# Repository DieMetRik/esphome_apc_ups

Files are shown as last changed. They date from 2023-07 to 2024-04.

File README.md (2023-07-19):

# UPS APC <-> ESP32 <-> Home Assistant

**disclaimer:** Сразу скажу, что я не проф. программист, поэтому код может где то быть не элегантен.

Мой UPS: **APC by Schneider Electric Smart-UPS SUA1500I**, Имеет на борту USB и RS232

За основу протокола: http://www.apcupsd.org/manual/#apc-smart-protocol

Cхема кабеля: http://www.apcupsd.org/manual/#id40

По итогу все работает, интервал обновления ~10 сек

Было проведено порядка 10 различных схем подключения и только на 10-11 получилось.

**Что тянется:**
* Входное напряжение
* Выходное напряжение
* Напряжение батареи
* Уровень заряд батареи
* Оставшееся время на батарее
* Нагрузка
* Температура
* Частота сети
* Последнее сообщение с UPS
* Статус bit 

**Что считается и передает в esp32:**
* Статус: ONLINE/OFFLINE/ONBATT
* Дата последнего обновления данных (время берется по NTP, нужно ESP в интернет)
* Кол-во переходов с ONLINE на ONBATT (Сохраняется в EEPROM)

Использовал сделующие компоненты:
* ESP32 38pin
* Logic Level shifter
* TTL <-> RS232
* DB9 male connector

Покупал тут:
* Esp32: https://aliexpress.ru/item/32864722159.html
* Logic Level shifter: https://aliexpress.ru/item/32247463702.html
* Вот эта у меня не заработала: https://pcus.ru/modul-preobrazovaniya-ttl-uart-v-rs232
* А вот эта норм: https://pcus.ru/max3232-preobrazovatel-rs232-db9-uart-ttl

Схема подключения:
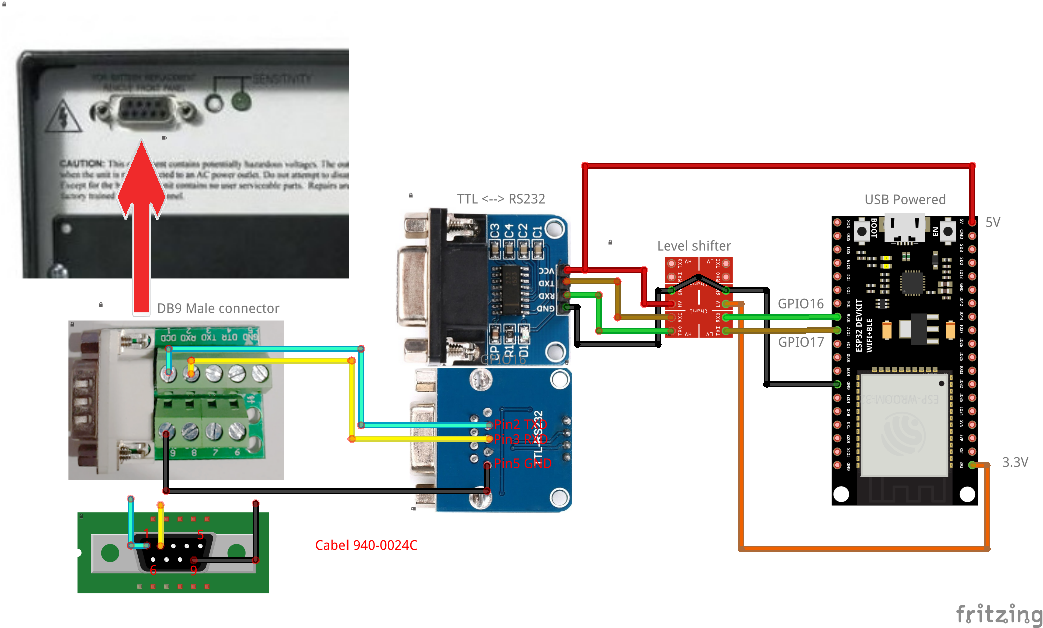
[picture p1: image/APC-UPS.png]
Image alt


Кабель:

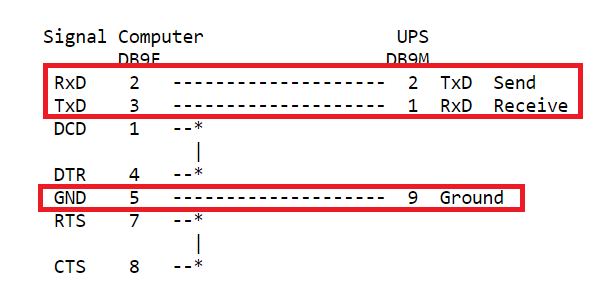
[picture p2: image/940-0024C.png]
Image alt


Код для ESPhome в файле /esp32/ups-apc-protocol.yaml
Папку /esp32/apc положить на сервер: /config/esphome/apc/

Пример для Home Assistant:

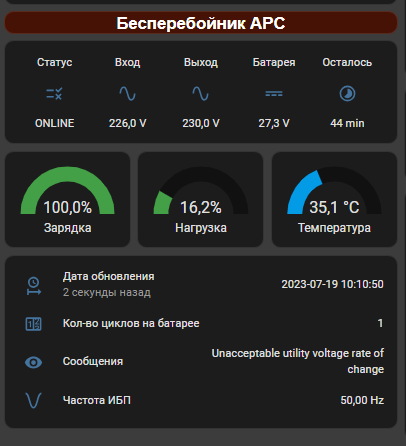
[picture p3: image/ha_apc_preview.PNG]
Image alt


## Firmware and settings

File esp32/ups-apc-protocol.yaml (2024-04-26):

substitutions:
  device_name: "ups-apc-protocol"
  device_ip: 192.168.1.137
  device_description: "Мониторинг бесперебойника"
  tx_pin: GPIO17
  rx_pin: GPIO16

esphome:
  name: ${device_name}
  name_add_mac_suffix: false
  includes:
    - /config/esphome/apc/upc_apc.h #Указываем свой путь до файла
  libraries:
    - EEPROM

  comment: ${device_description}
  on_boot:
    if:
      condition:
        time.has_time:
      then:
        - logger.log: Time has been set and is valid!

esp32:
  board: esp32dev
  framework:
    type: arduino

web_server:
  port: 80
  include_internal: true
  version: 3
  auth:
    username: !secret web_server_login
    password: !secret web_server_password

# Enable logging
logger:
  level: debug

# Enable Home Assistant API
api:
  encryption:
    key: !secret encryption_key_ups_apt_protocol

ota:
  password: !secret ota_password

wifi:
  ssid: !secret wifi_ssid
  password: !secret wifi_password

  # Optional manual IP
  manual_ip:
    static_ip: ${device_ip}
    gateway: !secret wifi_gateway
    subnet: !secret wifi_subnet
    dns1: !secret wifi_dns1
    dns2: !secret wifi_dns2

  # Enable fallback hotspot (captive portal) in case wifi connection fails
  ap:
    ssid: ${device_name}
    password: !secret ap_password

captive_portal:

time:
  - platform: sntp
    servers: "192.168.1.30"
    id: sntp_time
    timezone: Europe/Moscow

text_sensor:
  - platform: version
    name: ${device_name}_version
    hide_timestamp: true

  - platform: template
    name: ${device_name}_uptime
    id: uptime_human
    icon: mdi:clock-start

  - platform: template
    name: ${device_name}_status
    id: Status
    lambda: "return {};"

  - platform: template     
    id: last_updated_datetime
    name: ${device_name}_last_updated_datetime
    icon: mdi:clock-start

  - platform: template     
    id: last_self_test_datetime
    name: ${device_name}_last_self_test_datetime
    icon: mdi:clock-start

  - platform: template     
    id: sensitivity
    name: ${device_name}_sensitivity
    icon: mdi:clock-start

  - platform: template
    name: ${device_name}_self_test_result
    id: self_test_result
    lambda: "return {};"
    on_raw_value:
      then:
      - text_sensor.template.publish:
          id: last_self_test_datetime
          state:  !lambda |-
              char str[25];
              time_t currTime = id(sntp_time).now().timestamp;
              strftime(str, sizeof(str), "%Y-%m-%d %H:%M:%S", localtime(&currTime));
              //strftime(str, sizeof(str), "%Y-%m-%dT%H:%M:%S.000Z", gmtime(&currTime));
              return (std::string) str;
    
  - platform: template
    name: ${device_name}_last_cause
    id: Last_cause
    lambda: "return {};"
    on_raw_value:
      then:
      - text_sensor.template.publish:
          id: last_updated_datetime
          state:  !lambda |-
              char str[25];
              time_t currTime = id(sntp_time).now().timestamp;
              strftime(str, sizeof(str), "%Y-%m-%d %H:%M:%S", localtime(&currTime));
              //strftime(str, sizeof(str), "%Y-%m-%dT%H:%M:%S.000Z", gmtime(&currTime));
              return (std::string) str;


sensor:
  - platform: wifi_signal
    name: ${device_name}_wifi_signal
    update_interval: 60s
    entity_category: "diagnostic"
    device_class: ""
    unit_of_measurement: "%"
    filters:
      - calibrate_polynomial:
          degree: 2
          datapoints:
              - -60.0 -> 67.0
              - -59.0 -> 68.0
              - -57.0 -> 71.0
              - -56.0 -> 72.0
              - -55.0 -> 73.0
              - -30.0 -> 96.0
              - -28.0 -> 98.0

  - platform: uptime
    name: ${device_name}_uptime
    id: uptime_sensor
    internal: true
    on_raw_value:
      then:
        - text_sensor.template.publish:
            id: uptime_human
            state: !lambda |-
              int seconds = round(id(uptime_sensor).raw_state);
              int days = seconds / (24 * 3600);
              seconds = seconds % (24 * 3600);
              int hours = seconds / 3600;
              seconds = seconds % 3600;
              int minutes = seconds /  60;
              seconds = seconds % 60;
              return (
                (days ? to_string(days) + "d " : "") +
                (hours ? to_string(hours) + "h " : "") +
                (minutes ? to_string(minutes) + "m " : "") +
                (to_string(seconds) + "s")
              ).c_str();

  - platform: template #estimated_runtime
    id: Estimated_runtime
    name: ${device_name}_estimated_runtime
    unit_of_measurement: "min"
    accuracy_decimals: 0
    lambda: "return {};"


  - platform: template #Input_voltage
    id: Input_voltage
    name: ${device_name}_input_voltage
    device_class: voltage
    state_class: measurement
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

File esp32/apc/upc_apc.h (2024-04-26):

//UPS APC ESPhome
//My telegram https://t.me/DieMetRik

#include "esphome.h"
#include "esphome/core/log.h"
#include "EEPROM.h"
#define EEPROM_SIZE 8

//namespace esphome {
//namespace mercury {

bool sw_selftest = false;
bool run_calibration_sw = false;
int interval_ups;

class Upcapc : public PollingComponent, public UARTDevice {
	Sensor *Estimated_runtime {nullptr};
	Sensor *Input_voltage {nullptr};
	Sensor *Temperature {nullptr};
	Sensor *Battery_level {nullptr};
	Sensor *Power_load {nullptr};
	Sensor *Output_voltage {nullptr};
	Sensor *Battery_voltage {nullptr};
	Sensor *Line_frequency {nullptr};
	BinarySensor *Runtime_calibration {nullptr};
	BinarySensor *Smart_trim {nullptr};
	BinarySensor *Smart_boost {nullptr};
	BinarySensor *On_line {nullptr};
	BinarySensor *On_battery {nullptr};
	BinarySensor *Overloaded_output {nullptr};
	BinarySensor *Battery_low {nullptr};
	BinarySensor *Replace_battery {nullptr};
	TextSensor *Last_cause {nullptr};
	TextSensor *Status {nullptr};
	Sensor *WorkOnBattery_count {nullptr};
	Sensor *Self_test_interval {nullptr};
	TextSensor *St_result {nullptr};

	Sensor *Return_threshold {nullptr};
	Sensor *Grace_delay {nullptr};
	Sensor *Wakeup_delay {nullptr};
	TextSensor *Sensitivity {nullptr};
	BinarySensor *Self_test_progress {nullptr};
	
	public:
	Upcapc(
	UARTComponent *parent, 
	Sensor *sensor1, 
	Sensor *sensor2, 
	Sensor *sensor3, 
	Sensor *sensor4, 
	Sensor *sensor5, 
	Sensor *sensor6, 
	Sensor *sensor7, 
	Sensor *sensor8,
	BinarySensor *sensor9,
	BinarySensor *sensor10,
	BinarySensor *sensor11,
	BinarySensor *sensor12,
	BinarySensor *sensor13,
	BinarySensor *sensor14,
	BinarySensor *sensor15,
	BinarySensor *sensor16,
	TextSensor *sensor17,
	TextSensor *sensor18,
	Sensor *sensor19,
	Sensor *sensor20,
	TextSensor *sensor21,
	Sensor *sensor22,
	Sensor *sensor23,
	Sensor *sensor24,
	TextSensor *sensor25,
	BinarySensor *sensor26
	) : UARTDevice(parent), 
	Estimated_runtime(sensor1),
	Input_voltage(sensor2),
	Temperature(sensor3),
	Battery_level(sensor4),
	Power_load(sensor5),
	Output_voltage(sensor6),
	Battery_voltage(sensor7),
	Line_frequency(sensor8),
	Runtime_calibration(sensor9),
	Smart_trim(sensor10),
	Smart_boost(sensor11),
	On_line(sensor12),
	On_battery(sensor13),
	Overloaded_output(sensor14),
	Battery_low(sensor15),
	Replace_battery(sensor16),
	Last_cause(sensor17),
	Status(sensor18),
	WorkOnBattery_count(sensor19),
	Self_test_interval(sensor20),
	St_result(sensor21),
	Return_threshold(sensor22),
	Grace_delay(sensor23),
	Wakeup_delay(sensor24),
	Sensitivity(sensor25),
	Self_test_progress(sensor26)
	{}
	
	//int sw_Self_test;
//common
	unsigned char params_smart_mode[1];			// Y
	unsigned char params_status[1];				// Q
//bool
	unsigned char params_bye[1];				// R

//double
	unsigned char params_input_voltage[1];		// L
	unsigned char params_temperature[1];		// C
	unsigned char params_battery_level[1];		// f
	unsigned char params_power_load[1];			// P
	unsigned char params_output_voltage[1];		// O = 4f
	unsigned char params_battery_voltage[1]; 	// B
	unsigned char params_estimated_runtime[1]; 	// j
	unsigned char params_line_frequency[1]; 	// F 
//Text sensor
	unsigned char params_last_cause[1]; 		// G
	unsigned char params_self_test_interval[1]; // E
	unsigned char params_self_test_run[1]; 		// W = 57
	unsigned char params_self_test_read[1];		// X = 58
	
	unsigned char params_return_threshold[1]; 	// e = 65
	unsigned char params_grace_delay[1]; 		// p = 70
	unsigned char params_wakeup_delay[1]; 		// r = 72
	unsigned char params_sensitivity[1]; 		// s = 73
	unsigned char params_run_calibration[1];	// D = 44	
	uint8_t Re_buf[40];
	int counter = 0;

	String status = "OFFLINE";
	
	int error_cnt = 0;
	int st_cnt = 0; //self test counter
	int total_error_cnt = 0;
	int step = 0;
	int prev_step = 0;

	bool b_self_test_progress = false;	//self test in progress
	bool wrk_on_btr = 0;
	bool wrk_on_btr_trig = 0;
	
	int address = 0;
	int32_t workonbattery_count;
	
//=======================================================
	void calculateParams(unsigned char *frame, unsigned char comm)
	{
		frame[0] = comm;
	}
//=======================================================
	int string2hex(char *s, uint8_t cnt){
		int x = 0;
		for(int i = 0;cnt;i++) {
			char c = *s;
			if (c >= '0' && c <= '9') {
				x *= 16;
				x += c - '0'; 
			}
			else if (c >= 'A' && c <= 'F') {
				x *= 16;
				x += (c - 'A') + 10; 
			}
			else break;
				s++;
		}
		return x;
	}
	
	double byteToFloat (uint8_t buf[], int cnt)
	{
		uint8_t tmp_buf[10];
		for (int i = 0;i<cnt; i++){
			tmp_buf[i]= buf[i];
		}
		String str1 = (char*)tmp_buf;
		double myDouble = str1.toDouble();
		return myDouble;
		
	}
	
	int byteToInt (uint8_t buf[], int cnt)
	{
		uint8_t tmp_buf[10];
		for (int i = 0;i<cnt; i++){
			tmp_buf[i]= buf[i];
		}
		String str1 = (char*)tmp_buf;
		int myInt = str1.toInt();
		return myInt;
		
	}
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

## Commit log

2023-07-19 apc release
    [APC-UPS.fzz]
2023-09-29 Update upc_apc.h
    update battery voltage for UPS with 4S battery
2023-09-29 Update Output voltage
    From nominal to real value
2023-10-01 Add some function
    Add ability to do self test from HA
    Add new sensors:
    - Self test result
    - Self test interval
    - Return threshold
    - Grace delay
    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
2023-10-01 Add new sensor + refactor self test
2023-10-01 Add calibration
    Add calibration
2023-10-02 Fix bit status of UPS
    [upc_apc.h]
